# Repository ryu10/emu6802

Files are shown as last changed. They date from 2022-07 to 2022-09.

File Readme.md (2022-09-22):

# EMU6802

[v0.6]

(日本語 | [EN](Readme_en.md))

  電脳伝説様作の [EMUZ80](https://github.com/vintagechips/emuz80) を利用した PIC16F47Q84 + MC6802 コンピュータです。

## TL;DR

 - [回路図](/img/emu6802_conv_sch.pdf)
 - [Gerber](/data/emu6802r1-gerber.zip)
 - [emu6802.X.production.hex](/data/emu6802.X.production.hex)（PIC16F47Q84 用）
 
## 機能と特徴

  - MC6802 用変換基板
  - RAM 12KB
  - Mikbug モニタ
  - Basic（フリーエリア 5.5KB）
  - PIC TU16A タイマモジュール（IRQ 割り込み可）

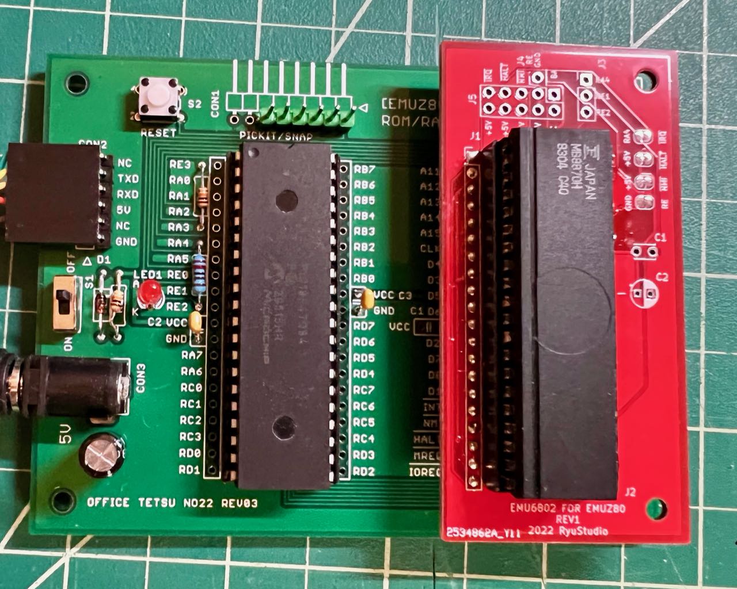
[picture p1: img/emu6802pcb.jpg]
emu6802


## 構成方法

以下の部品が必要です。

 - EMUZ80 キット（Z80 を除く）
 - PIC16F47Q84
 - EMU6802 変換基板（[Gerber](/data/emu6802r1-gerber.zip)）
 - MC6802 または互換チップ
 - DIP 40P ソケット
 - 20x1 ピンソケット x2
 - 20x1 ピンヘッダ x2（細ピンタイプ、秋月電子などで入手可）
 - （オプション）C1/C2 パスコン（0.1uF, 10uF）、J3/J4/J5 パッチベイ用ピンヘッダ（5x2, 1x1, 3x1）

上の画像では MC6802 互換の MB8870H を使用しています。

## 配線

変換基板の配線を下の回路図に示します（[PDF 版](/img/emu6802_conv_sch.pdf)）。標準でデータバス、アドレスバス、制御信号、IRQ が配線されています。

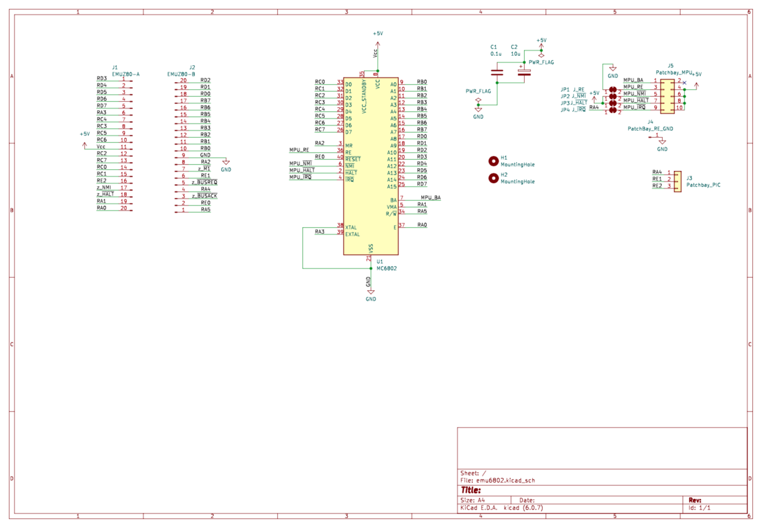
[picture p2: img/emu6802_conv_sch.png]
schematic


## PIC プログラム

HEX ファイル [emu6802.X.production.hex](/data/emu6802.X.production.hex) を PIC へ書き込みます（PIC18F47Q84 用です）。ソースコードは [emu6802.X](/emu6802.X/) 以下を参照してください。プロジェクトは MPLAB X IDE で開きます。

## BASIC 実行までの手順

1. EMUZ80 を組み立てます。PIC18F47Q84 を使用します。Z80 は取り付けません。
2. Z80 ソケットの外側のパターンに 20x1 ピンソケット 2 本をはんだ付けします。
3. PIC に HEX ファイル [emu6802.X.production.hex](/data/emu6802.X.production.hex) を書き込みます。なお PIC 書き込みの際は念のため 6802 または変換基板を取り外してください。
4. 変換基板を組み立てて EMUZ80 基板のピンソケットに刺します。
5. 電源投入すると EMUZ80 のシリアルポート（9600bps）から Mikbug を使用できます。
6. 'G' コマンドが参照するジャンプベクタアドレスは $2F48-$2F49です。デフォルトでジャンプベクタ $0000 が設定されているので、電源投入後すぐに 'G' キーを押すと Basic が立ち上がります。起動時の質問には下記の画面のとおり順に「12160」「80」「Y」と答えると一般的な設定が選択されます。

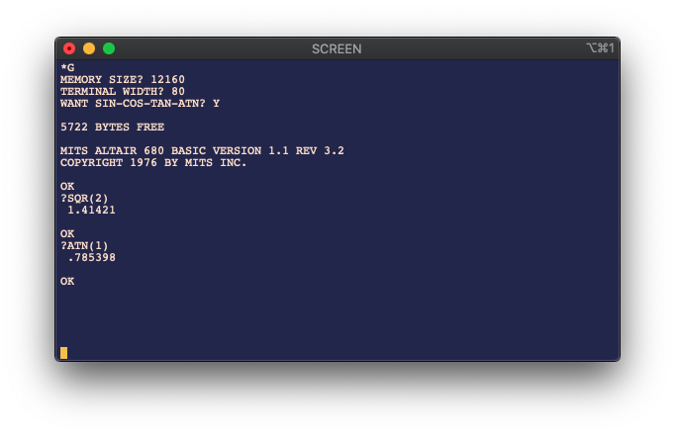
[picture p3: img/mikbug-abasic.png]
startup-mikbug-altair


## 動作

EMUZ80 と同様に PIC が MPU バス信号を読み取って ROM、RAM、UART、タイマをエミュレートします。通常のハードウェアに比べてメモリ応答が遅くなるので、6802 の MR ピンを使ってシステムクロック E をストレッチしています。現状のコードでは、外部クロック入力 EXTAL に 2.3MHz を入力した場合に BASIC プログラムが最も高速に動作するようです。このとき 6802 のシステムクロック E は 387kHz 程度です。

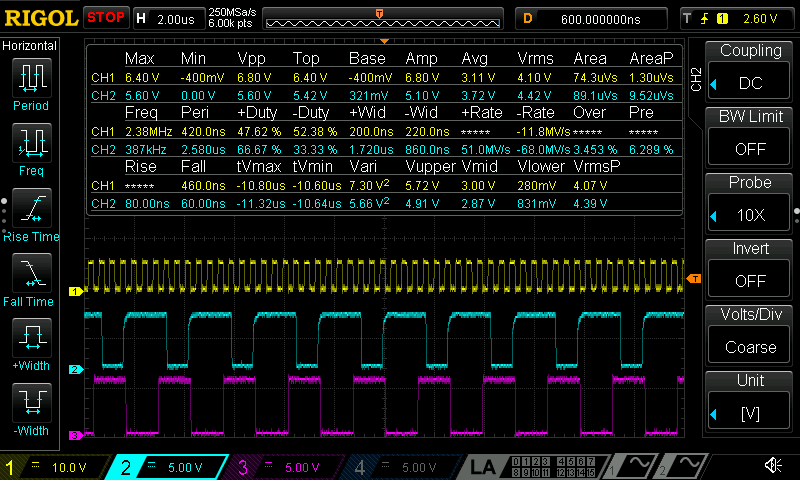
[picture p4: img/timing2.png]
timing2


（Ch1: EXTAL, Ch1: E, Ch3: MR）

## PIC タイマと IRQ 割り込み

PIC タイマモジュール TU16A の出力が CLC の FF 回路を経由して 6802 の IRQ に接続されます。6802 メモリ空間の \$A007 - \$A00F で TU16A の設定レジスタにアクセスできます。アドレスとレジスタの対応は下表のとおりです。

| 6802 アドレス | PIC レジスタ名  |
|---|---|
| 0xa007 | TU16ACON0 |
| 0xa008 | TU16ACON1 |
| 0xa009 | TU16AHLT |
| 0xa00a | TU16APS |
| 0xa00b | TU16ATMRH / TU16ACRH |
| 0xa00c | TU16ATMRL / TU16ACRL |
| 0xa00d | TU16APRH |
| 0xa00e | TU16APRL |
| 0xa00f | TU16ACLK |
| 0xa01f | IRQ フラグリセット |

タイマ割り込みを応用した MC6802 時計表示プログラムが [clock.a](data/irq/clock.a) です。

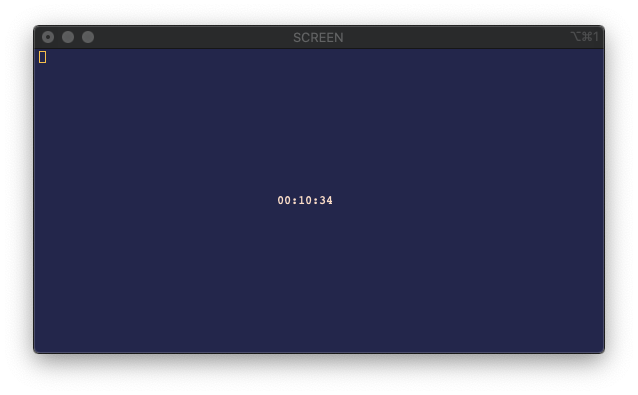
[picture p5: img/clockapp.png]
clockapp


また PIC コードによって動く RTC がプログラムされており、RTC の時刻データを \$B000 - \$B003 で読み書きできるようにしてあります。\$B010 への書き込みアクセスをしたタイミングで時刻がセットされます。この場合 IRQ 割り込みは不要です。これを利用した Basic 時計表示プログラムが [clock.bas](data/pictmr/clock.bas) です。

なお PIC の内部発振は誤差 2% 程度なので、実用的な RTC としては精度が不十分です。

## 課題

- PIC のメモリエミュレーションを最適化する。✅
- Altair 680 Basic を走らせる。✅
- 割り込みピンを配線する。✅
- EMUZ80 基板に載せられるアダプタボードを作る。✅
- ~~MC6802 内蔵 128 Byte RAM を有効にする。✅~~（※本リリースのデフォルト設定では無効。[リリース v0.33](https://github.com/ryu10/emu6802/tree/v0.33) を参照してください）

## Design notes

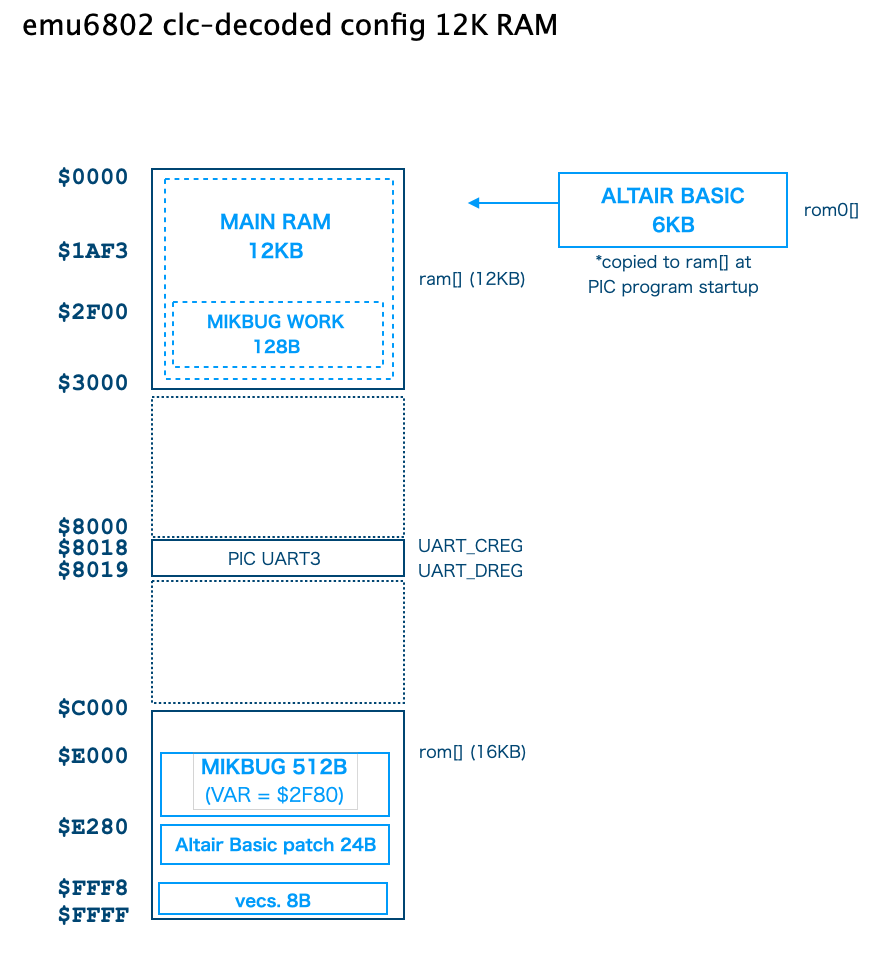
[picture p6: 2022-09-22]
img/emu6802-abasic-mmap.png

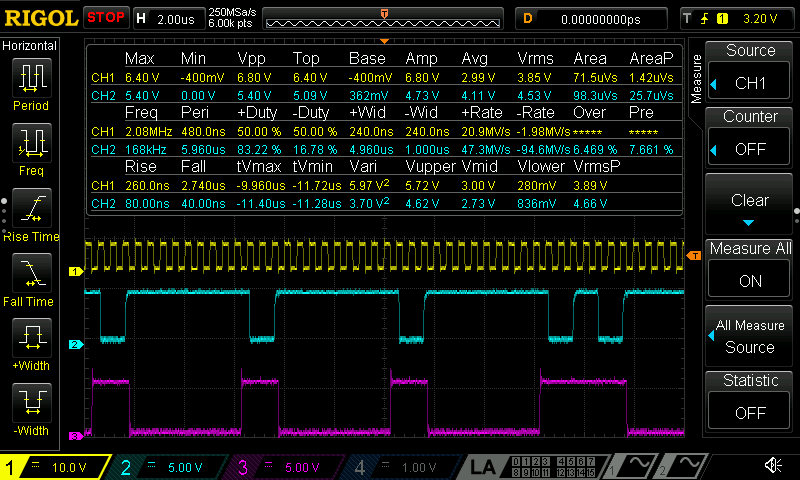
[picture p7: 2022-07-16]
img/timing.png

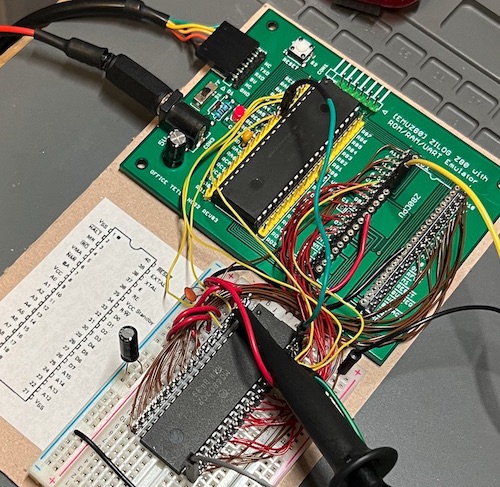
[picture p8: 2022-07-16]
img/emu6802bb.jpg

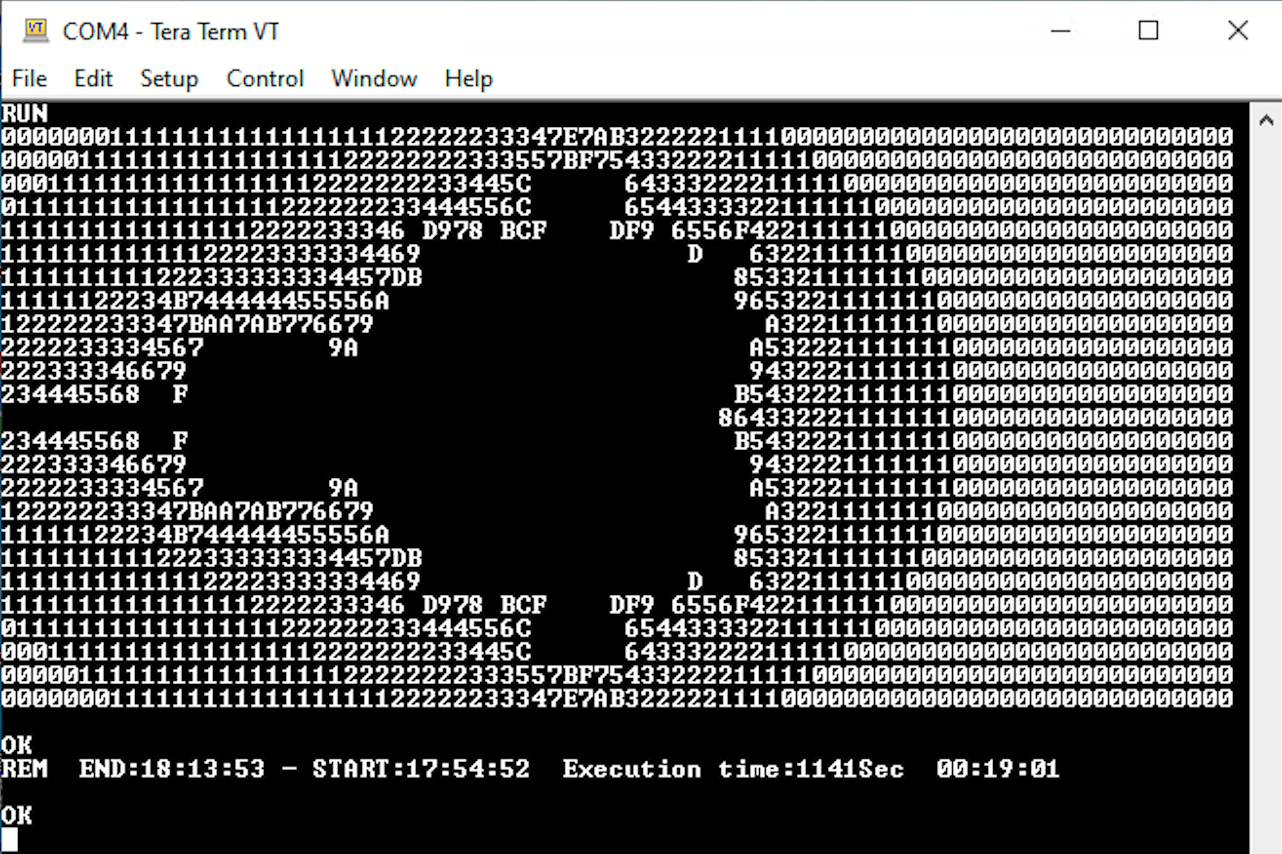
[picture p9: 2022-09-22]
img/asciiart.png

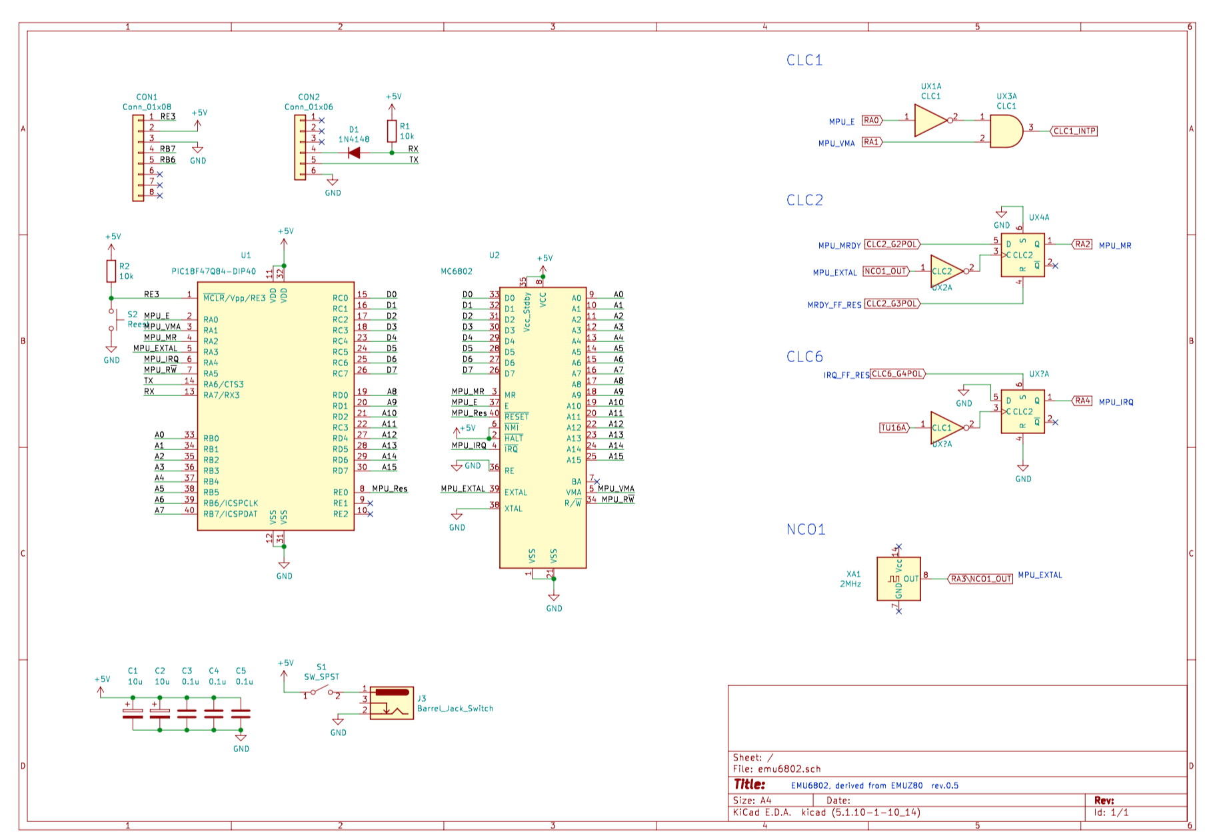
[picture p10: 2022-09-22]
img/emu6802_sch.png

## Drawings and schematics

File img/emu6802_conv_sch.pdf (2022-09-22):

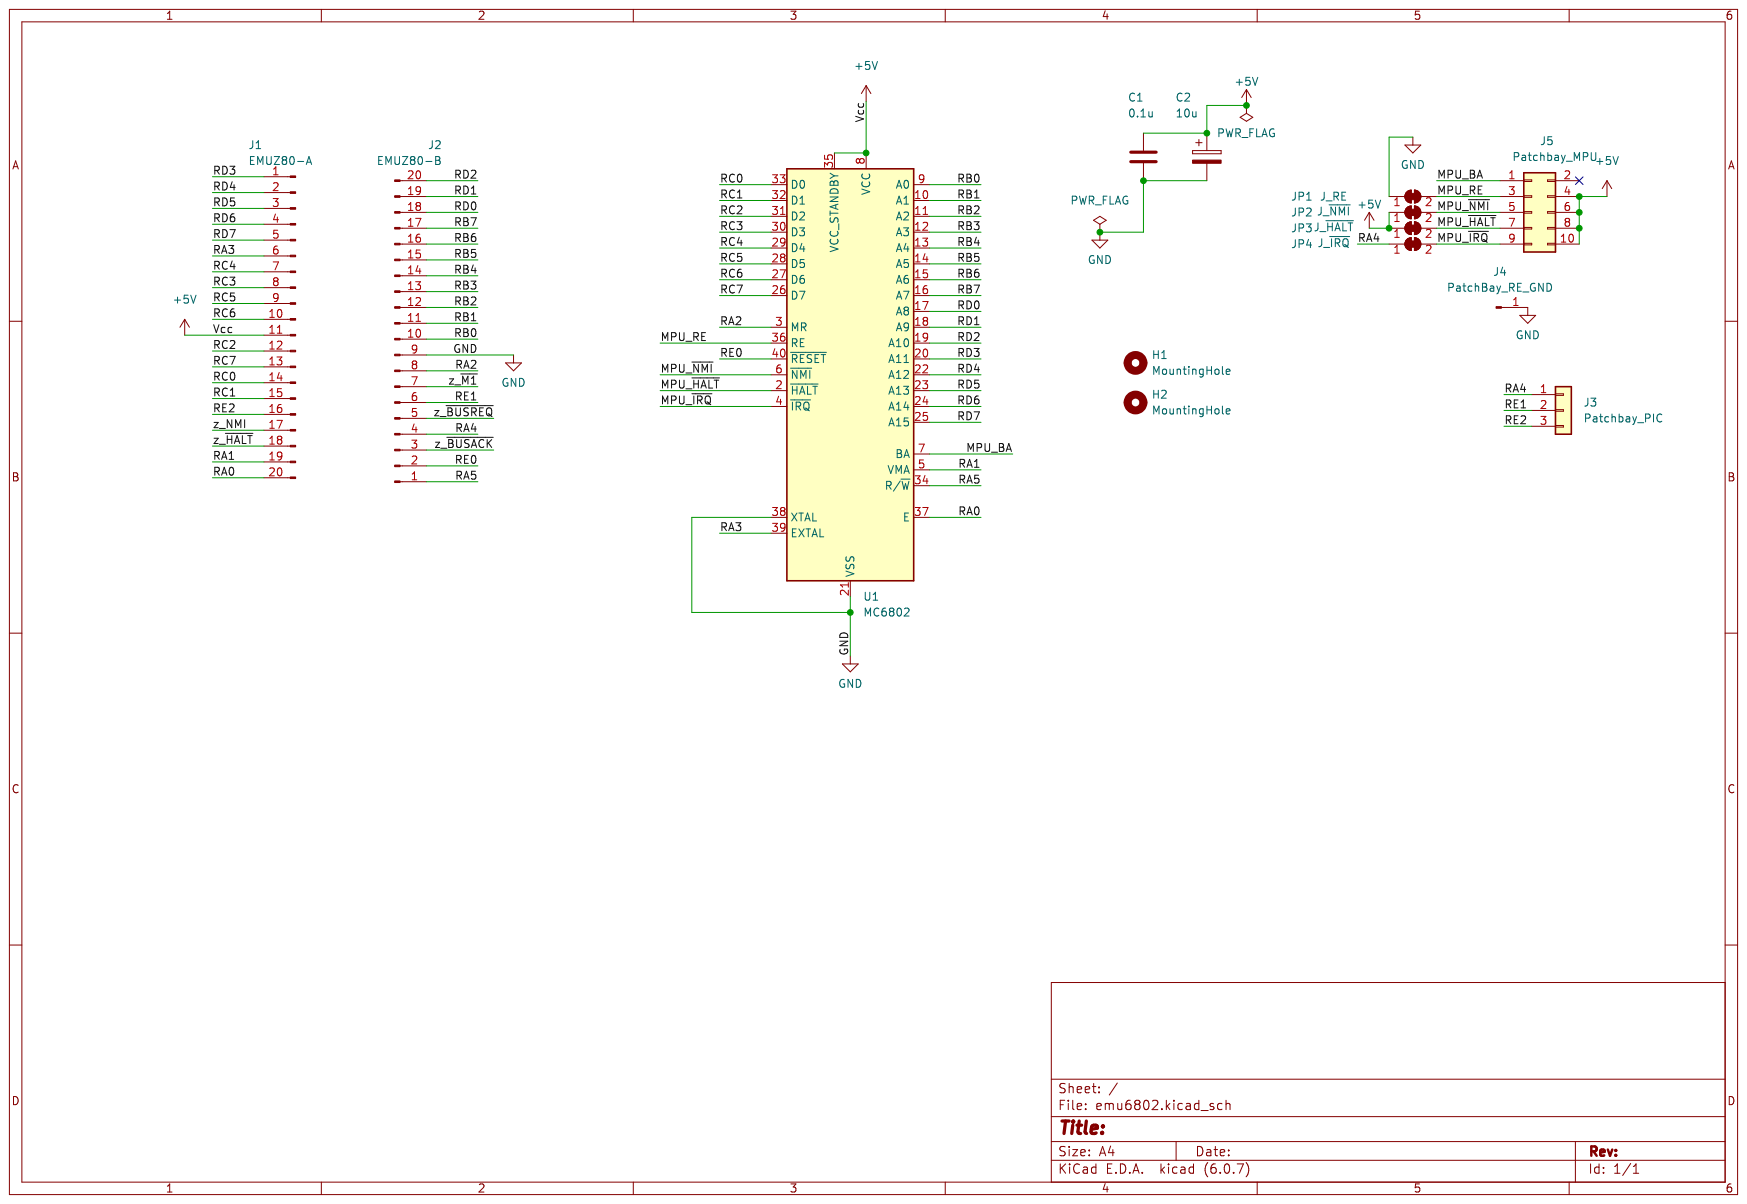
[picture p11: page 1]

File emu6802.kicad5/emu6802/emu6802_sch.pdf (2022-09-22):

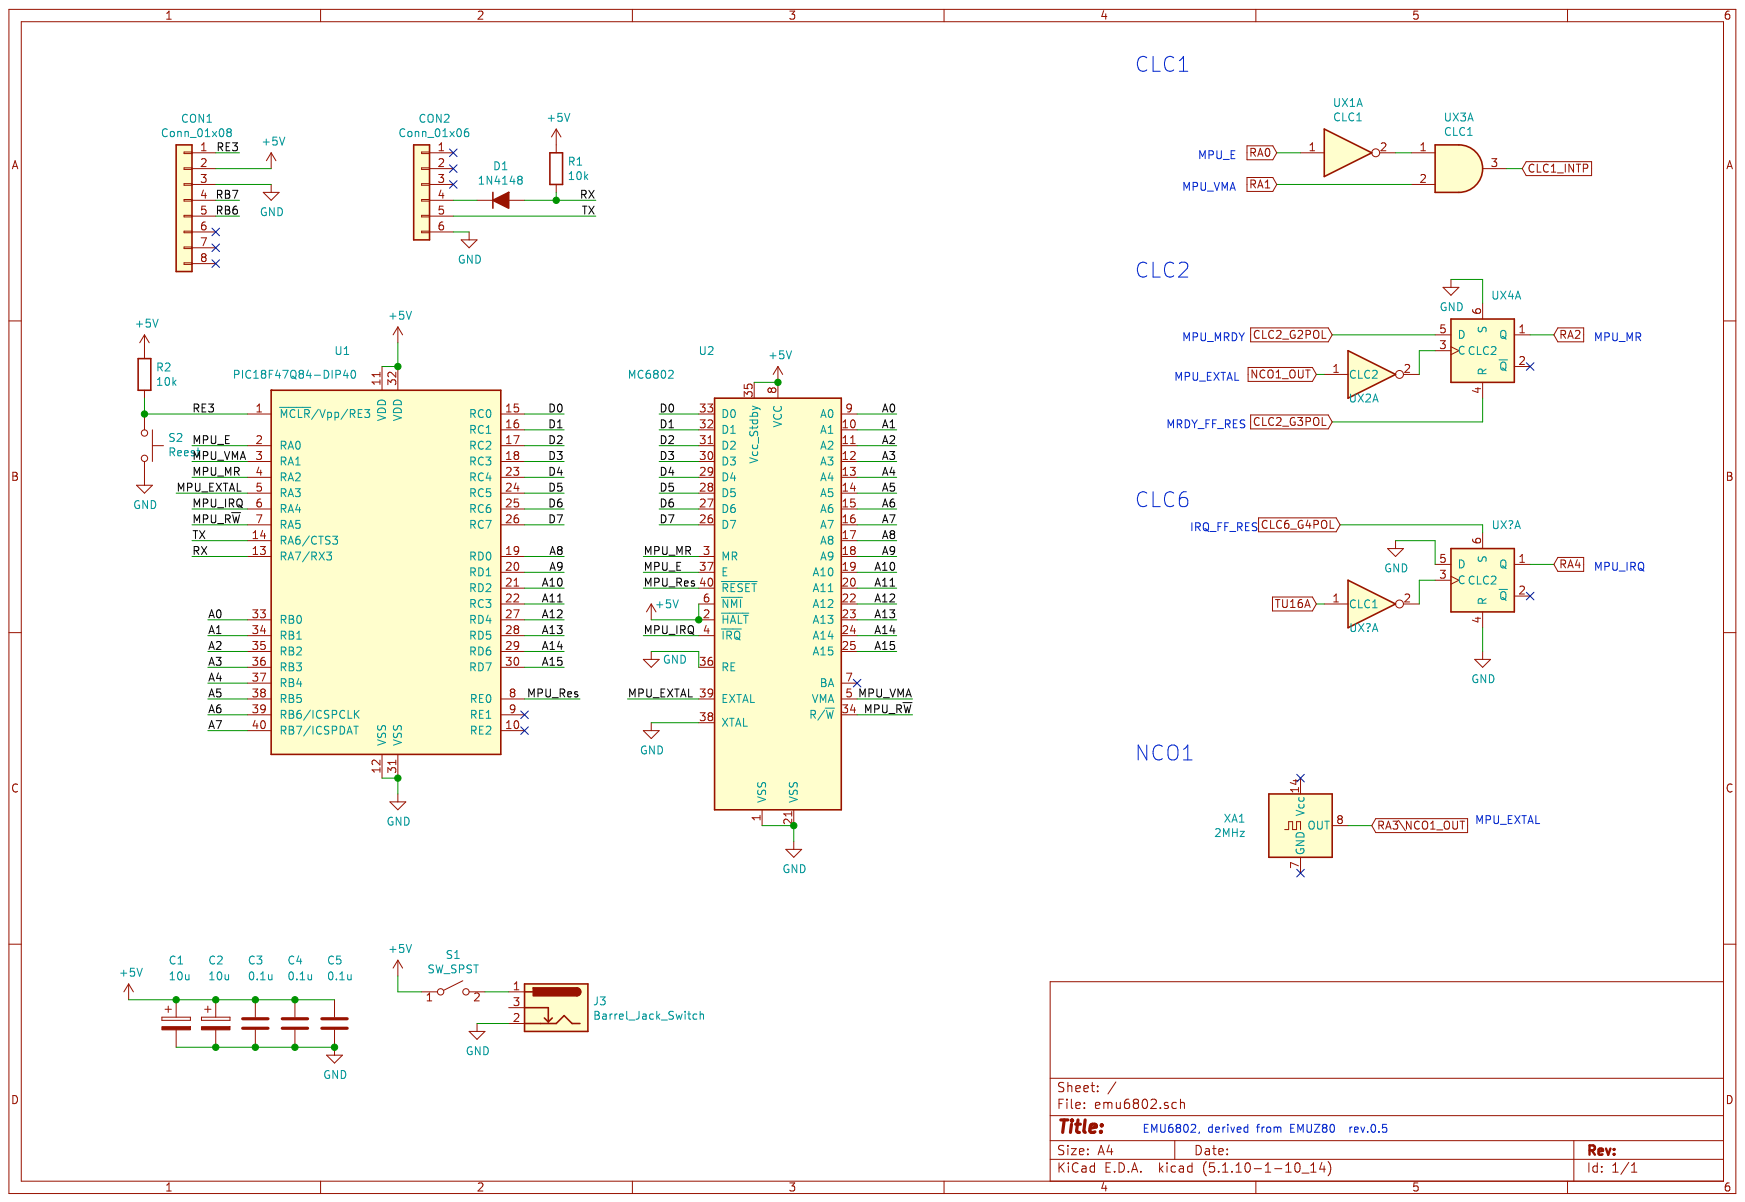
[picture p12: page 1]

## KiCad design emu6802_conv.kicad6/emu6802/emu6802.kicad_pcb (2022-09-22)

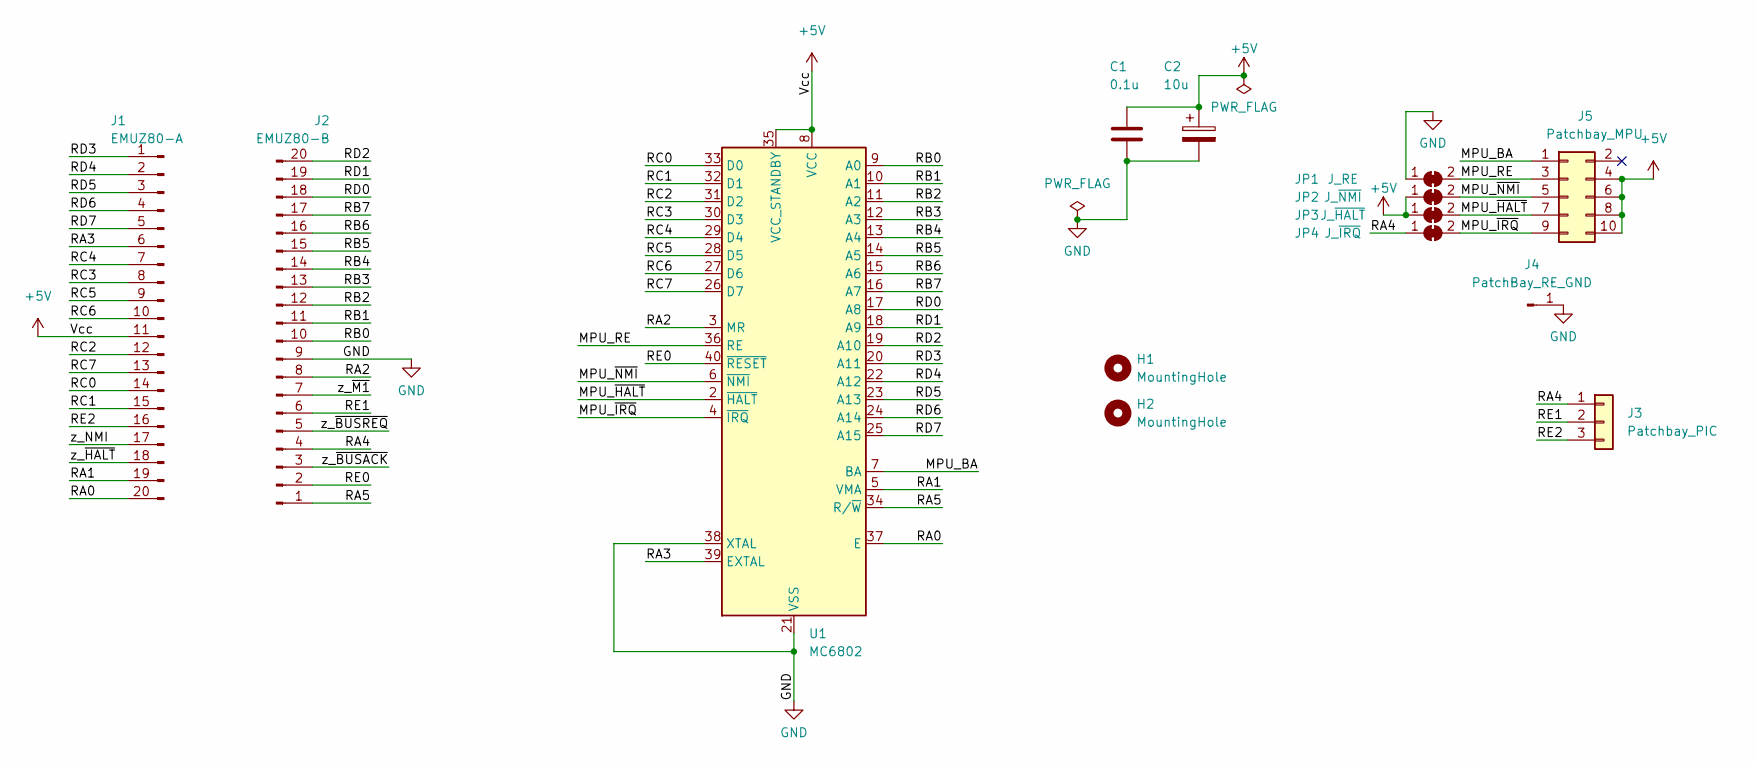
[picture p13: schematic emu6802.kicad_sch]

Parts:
C1: 0.1u; C_Disc_D3.0mm_W2.0mm_P2.50mm
C2: 10u; CP_Radial_D4.0mm_P2.00mm
H1, H2: MountingHole; MountingHole_3.2mm_M3
J1: EMUZ80-A; PinHeader_1x20_P2.54mm_Vertical
J2: EMUZ80-B; PinHeader_1x20_P2.54mm_Vertical
J3: Patchbay_PIC; PinHeader_1x03_P2.54mm_Vertical
J4: PatchBay_RE_GND; PinHeader_1x01_P2.54mm_Vertical
J5: Patchbay_MPU; PinHeader_2x05_P2.54mm_Vertical
JP1: J_RE; SolderJumper-2_P1.3mm_Bridged_RoundedPad1.0x1.5mm
JP2: J_~{NMI}; SolderJumper-2_P1.3mm_Bridged_RoundedPad1.0x1.5mm
JP3: J_~{HALT}; SolderJumper-2_P1.3mm_Bridged_RoundedPad1.0x1.5mm
JP4: J_~{IRQ}; SolderJumper-2_P1.3mm_Bridged_RoundedPad1.0x1.5mm
U1: MC6802; DIP-40_W15.24mm

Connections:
+5V: C1.1, C2.1, J1.11, J5.4, J5.6, J5.8, J5.10, JP2.1 (A), JP3.1 (A), U1.8 (VCC), U1.35 (VCC_STANDBY)
/MPU_BA: J5.1, U1.7 (BA)
/MPU_RE: J5.3, JP1.2 (B), U1.36 (RE)
/MPU_~HALT: J5.7, JP3.2 (B), U1.2 (~HALT)
/MPU_~IRQ: J5.9, JP4.2 (B), U1.4 (~IRQ)
/MPU_~NMI: J5.5, JP2.2 (B), U1.6 (~NMI)
/RA0: J1.20, U1.37 (E)
/RA1: J1.19, U1.5 (VMA)
/RA2: J2.8, U1.3 (MR)
/RA3: J1.6, U1.39 (EXTAL)
/RA4: J2.4, J3.1, JP4.1 (A)
/RA5: J2.1, U1.34 (R/~W)
/RB0: J2.10, U1.9 (A0)
/RB1: J2.11, U1.10 (A1)
/RB2: J2.12, U1.11 (A2)
/RB3: J2.13, U1.12 (A3)
/RB4: J2.14, U1.13 (A4)
/RB5: J2.15, U1.14 (A5)
/RB6: J2.16, U1.15 (A6)
/RB7: J2.17, U1.16 (A7)
/RC0: J1.14, U1.33 (D0)
/RC1: J1.15, U1.32 (D1)
/RC2: J1.12, U1.31 (D2)
/RC3: J1.8, U1.30 (D3)
/RC4: J1.7, U1.29 (D4)
/RC5: J1.9, U1.28 (D5)
/RC6: J1.10, U1.27 (D6)
/RC7: J1.13, U1.26 (D7)
/RD0: J2.18, U1.17 (A8)
/RD1: J2.19, U1.18 (A9)
/RD2: J2.20, U1.19 (A10)
/RD3: J1.1, U1.20 (A11)
/RD4: J1.2, U1.22 (A12)
/RD5: J1.3, U1.23 (A13)
/RD6: J1.4, U1.24 (A14)
/RD7: J1.5, U1.25 (A15)
/RE0: J2.2, U1.40 (~RESET)
/RE1: J2.6, J3.2
/RE2: J1.16, J3.3
/z_NMI: J1.17
/z_~BUSACK: J2.3
/z_~BUSREQ: J2.5
/z_~HALT: J1.18
/z_~M1: J2.7
GND: C1.2, C2.2, J2.9, J4.1, JP1.1 (A), U1.1 (VSS), U1.21 (VSS), U1.38 (XTAL)

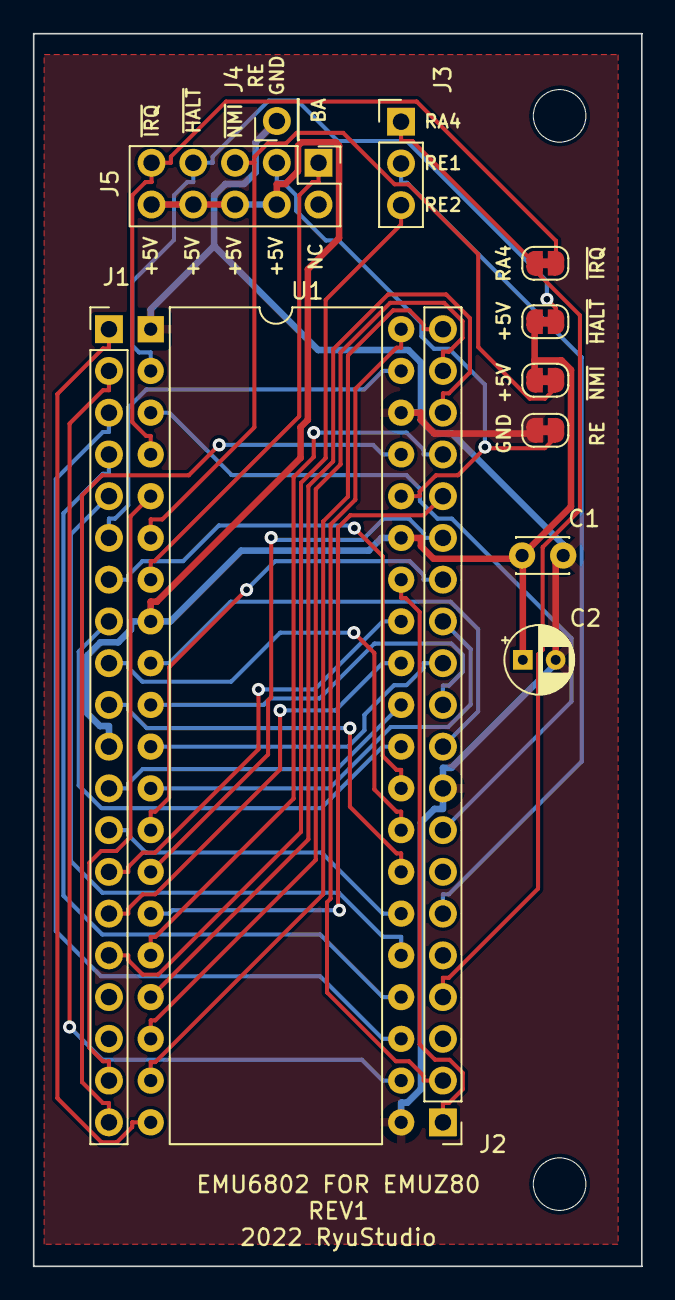
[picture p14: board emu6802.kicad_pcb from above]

Board: 2 copper layers, 37.0 x 75.0 mm, 14 parts (0 on the bottom side), 40 nets.

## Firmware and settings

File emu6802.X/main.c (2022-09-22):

/* 
 * File:   main.c
 * Author: ryu10/RyuStudio
 *
 * Created on July 5, 2022, 11:20 PM
 */

#include "mcc_generated_files/mcc.h"
#include <stdio.h>
#include <stdlib.h>
#include "PortAssign.h"
#include "MemAccess.h"
#include "RomRam.h"
#include "ClockTimer.h"

/*
 * main
 */

int main(int argc, char** argv) {

    // Initialize the device
    SYSTEM_Initialize();

    // update pin input slew rate
//    SLRCONA = 0;
//    SLRCONB = 0;
//    SLRCONC = 0;
//    SLRCOND = 0;
//    SLRCONE = 0;

    // init romram;
    // done in "RomRam.h"

    // Assert MPU Reset#
    MPU_RES = 0;
    
    // set databus MPU write default
    MPU_DDIR = 0xff;

    // // set RA4 ODCON - Open Drain
    // ODCONAbits.ODCA4 = 1;
    
    // set IRQ FF
    CLCSELECT = 5; // select CLC6 = IRQ FF
    __delay_us(1);
    IRQ_FF_RES = 1;
    __delay_us(1);
    IRQ_FF_RES = 0;

    // reset MRdy FF
    CLCSELECT = 1; // select CLC2=MRdy FF
    MRDY_FF_RES = 0;
    __delay_us(1);
    MRDY_FF_RES = 1;
    __delay_us(1);
    MRDY_FF_RES = 0;
    
    // Assert MPU MemRdy (normal operation)
    __delay_us(1);
    MPU_MRDY = 1;
    // leave CLC2 selected for future access

    // init Clock Timer
    clockInit();

    // copy altair basic img to ram0[] area]
    cp_basic();

    // set mikbug 'G' vector to 0x0000 abasic start address
    ram[0x2f48 - RAM_BEG] = 0x00;
    ram[0x2f49 - RAM_BEG] = 0x00;
    
    // Enable global interrupts
    INTERRUPT_GlobalInterruptHighEnable();

    // Print startup mesg.
    printf("MPU init done\r\n");

    // Release MPU Reset#
    __delay_us(5);
    MPU_RES = 1;

    while(1) {
      if(!CLCDATAbits.CLC6OUT){
        reset_tmrout = 1; // let isr reset CLC6OUT;
        __delay_us(20);  // let isr work
        curr_time[0]++; //tick
        if(curr_time[0]==10){
          curr_time[0]=0;
          curr_time[1]++; //sec
          if(curr_time[1]==60){
            curr_time[1]=0;
            curr_time[2]++; //min
            if(curr_time[2]==60){
              curr_time[2]=0;
              curr_time[3]++; //hr
              if(curr_time[3]==24){
                curr_time[3]=0;
              }
            }
          }
        }
      }
    }

    return (EXIT_SUCCESS);

}

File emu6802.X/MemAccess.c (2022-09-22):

/* 
 * File:   MemAccess.c
 * Author: ryu
 *
 * Created on July 31, 2022, 9:49 AM
 */

#include <stdio.h>
#include <stdlib.h>
#include "RomRam.h"
#include "PortAssign.h"
#include "MemAccess.h"

/*
 * 
 */

void memAccess(){
    asm("movff    PORTB,TBLPTRL");
    asm("movff    PORTD,TBLPTRH");
    asm("bcf    CLCnPOL,1"); // MPU_MRDY = 0; // G2POL = 0; CLCnPOL,1

    PIR0bits.CLC1IF = 0;     // Clear the CLC interrupt flag
    if(MPU_RW){
        // MPU read = PIC Data bus output
          asm("clrf    TRISC");        // MPU_DDIR = 0;
          if(TBLPTRH < (RAM_END>>8)){ // main ram
          asm("movf    PORTB,w");
          asm("movwf   FSR0L");
          asm("movlw   0x10");
          asm("addwf   PORTD,w");
          asm("movwf   FSR0H");
          asm("movf    INDF0,w");
          asm("movwf   LATC");
        }else if(TBLPTRH >= (ROM_BEG>>8)){ // 16k rom
          asm("movf    PORTB,w");
          asm("movwf   TBLPTRL");
          asm("movf    PORTD,w");
          asm("movwf   TBLPTRH");
          asm("clrf    TBLPTRU");
          asm("tblrd");
          asm("movf    TABLAT,w");
          asm("movwf   LATC");
        }else if(TBLPTRH == (UART_DREG>>8)){
          if(TBLPTRL == (UART_DREG & 0x00ff)){
            asm("movff U3RXB,LATC");
          }else{
          asm("movff PIR9,LATC");
          }
        }
        // Clear Mem Stretch
        asm("bsf    CLCnPOL,1"); // MPU_MRDY = 1; // G2POL = 1; CLCnPOL,1
        // after a write phase, we should wait for at least tDHW = 30ns here but omit it for now
        asm("setf    TRISC");        // MPU_DDIR = 0xff;
    }else{
        // MPU write = PIC Data bus input
        if(TBLPTRH < (RAM_END>>8)){ // main ram
          asm("movf    PORTB,w");
          asm("movwf   FSR0L");
          asm("movlw   0x10");
          asm("addwf   PORTD,w");
          asm("movwf   FSR0H");
          while(MPU_E==0){;} // wait until the second half of MPU cycle
          _delay(4); // 62.5ns * 4 = 250ns; cf. tDDW = 225ns @MC6802
          asm("movf    PORTC,w");
          asm("movwf   INDF0");
        }else if(TBLPTRH == (UART_DREG>>8)){
          if(TBLPTRL == (UART_DREG & 0x00ff)){
            while(MPU_E==0){;} 
            _delay(4); // 62.5ns * 4 = 250ns; cf. tDDW = 225ns @MC6802
            asm("movff PORTC,U3TXB"); // U3TXB = PORTC;
          }
        }
        // Clear Mem Stretch
        asm("bsf    CLCnPOL,1"); // MPU_MRDY = 1; // G2POL = 1; CLCnPOL,1
    }
}

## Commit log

2022-07-16 add schematic and readme
    [emu6802.kicad_pcb, emu6802.sch]
2022-07-16 add schematic img to readme
2022-07-17 allocate sparse ram locations; does not work with altair basic
    [main.c]
2022-07-24 update readmes
    [emu6802.sch]
2022-08-03 rewrite rom/ram r/w with inline assembly; working
2022-08-03 reorder write: ram-rom-uart; barely improved; working
2022-08-03 move memory access code to clc.1, written in inline assembly; working
2022-08-06 runs at 2.3MHz Extal, with single stretch for RAM access and multiple for ROM and UART
2022-08-07 add more inline assembly in clc1.c; fastest asciiart so far 19:01
2022-08-08 replace schematic PDF
2022-08-09 update schematic
    [emu6802.sch]
2022-08-13 init irq branch working
    [emu6802.sch]
2022-08-13 in-PIC timer version
2022-09-22 update readme for pictmr, master v0.6 candidate
    [emu6802-B_Cu.gbl, emu6802-B_Mask.gbs, emu6802-B_Silkscreen.gbo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]
